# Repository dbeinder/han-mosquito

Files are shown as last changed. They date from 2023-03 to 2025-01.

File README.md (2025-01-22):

# µHAN mosquito

> **_Aus Österreich?:_** Ich habe noch einige Module übrig, bei Interesse bitte Email an david(at)beinder.at
> 
>  Inkl. Versand 37€ für 1 Stk, dann +15€ für jedes weitere. Privatverkauf, Bastellösung, keine Gewährleistung, etc ;)

A tiny [M-BUS](https://m-bus.com/documentation-wired/04-physical-layer)-powered [ESP32-C3](https://www.espressif.com/sites/default/files/documentation/esp32-c3_datasheet_en.pdf) board to capture data from digital electricity meters. Compatible with [AMS reader](https://github.com/UtilitechAS/amsreader-firmware) firmware.

  - Power & flashing via USB-C
  - Power & meter signal via M-BUS (RJ11)
    - Input current limited to 40mA, this is probably only compatible with Kaifa meters
    - Firmware needs no aggressive WiFi power management, there is enough for AP mode and OTA firmware upgrade
  - ESP32-C3-MINI-1 module: 160MHz RISC-V core, 4MB Flash, 400kB RAM, 2.4GHz WiFi
  - 1mm² RGB LED
  - Two side-mounted buttons
    - Top: ESP32 reset
    - Bottom: AP mode, hold during reset to flash
  - Mounted by magnet on the IR port
  - Tested on an Austrian (Vbg) Kaifa MA309M
  - Designed in KiCad 7
  
License: free to use and modify for non-commercial use

panel
proto-mounted

###  Prototype pictures
  
| proto-front  | proto-back |
| --- | --- |
|   | |

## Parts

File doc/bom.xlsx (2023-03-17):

Description | LCSC | Package | Name | Designator | $/pcs | pcs | $ | JLCPCB Extended Part | THT
5303-6P6C | C3097718 |  | RJ11 connector | J1 | 0.072 | 1 | 0.072 | 1 | 1
U264-141N-4BAC10 | C692526 |  | USB-C connector | J2 | 0.7492 | 1 | 0.7492 | 1 | 1
GT-TC018A-H035-L1 | C778153 |  | side NO switch | SW1, SW2 | 0.0291 | 2 | 0.0582 | 1
ESP32-C3-MINI-1-H4 | C2934569 |  | ESP32-C3 module | U1 | 2.1063 | 1 | 2.1063 | 1
TP6841S6 | C2844736 | SOT-23-6 | DC/DC, 800kHz | U2 | 0.4169 | 1 | 0.4169 | 1
MSK4010 | C345958 | SOD-523 | schottky | D2, D3, D5 | 0.0295 | 3 | 0.0885 | 1
BZX584C6V8 | C83014 | SOD-523 | zener 6V2 | D6 | 0.0268 | 1 | 0.0268 | 1
FC-B1010RGBT-HG | C158099 | 0404 | RGB LED | D7 | 0.0192 | 1 | 0.0192 | 1
AL5809-40S1-7 | C151420 | SOD-123 | diode driver 40mA | D1 | 0.5031 | 1 | 0.5031 | 1
MMBT3906T | C61615 | SOT-523-3 | PNP | Q1 | 0.024 | 1 | 0.024 | 1
NPXC0901V151MF | C2976307 |  | 150uF 35V D6.3mm, H7mm | C1 | 0.164 | 1 | 0.164 | 1 | 1
CL10A226MO7JZNC | C2762594 | 0402 | 22uF, 16V | C4, C5 | 0.0543 | 2 | 0.1086 | 1
GRM188R6YA106MA73D | C194427 | 0402 | 10uF, 35V | C2, C3 | 0.037 | 2 | 0.074 | 1
CL05B104KB54PNC | C307331 | 0402 | 100nF, 50V | C6, C7, C9 | 0.0031 | 3 | 0.0093 | 0
GRM155R6YA225KE11D | C237392 | 0402 | 2.2uF, 35V | C8 | 0.0417 | 1 | 0.0417 | 1
CKST252012-6.8uH/M | C3002554 | 252012 | 6.8uH | L1 | 0.0609 | 1 | 0.0609 | 1
0402WGF7502TCE | C25798 | 0402 | 75k, 1% | R1 | 0.0005 | 1 | 0.0005 | 0
0402WGF2402TCE | C25769 | 0402 | 24k, 1% | R2 | 0.0005 | 1 | 0.0005 | 0
0402WGF1004TCE | C26083 | 0402 | 1M, 1% | R3, R7, R8 | 0.0005 | 3 | 0.0015 | 0
0402WGF3300TCE | C25104 | 0402 | 330R, 1% | R4 | 0.0005 | 1 | 0.0005 | 0
0402WGF2201TCE | C25879 | 0402 | 2.2k, 1% | R5 | 0.0005 | 1 | 0.0005 | 0
0402WGF1001TCE | C11702 | 0402 | 1k, 1% | R6 | 0.0005 | 1 | 0.0005 | 0
0402WGF2003TCE | C25764 | 0402 | 200k, 1% | R9, R12 | 0.0005 | 2 | 0.001 | 0
0402WGF5101TCE | C25905 | 0402 | 5.1k, 1% | R10, R11 | 0.0005 | 1 | 0.0005 | 0

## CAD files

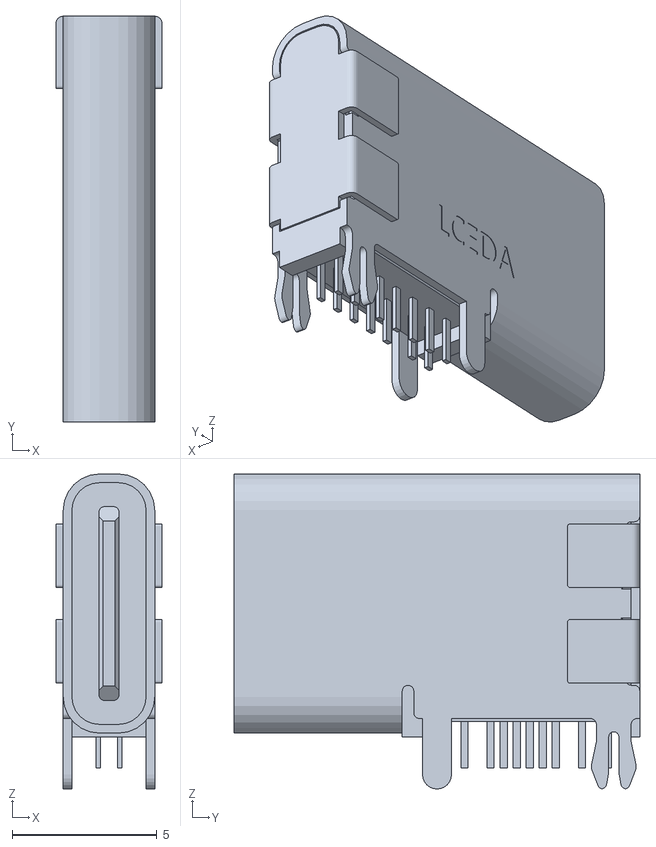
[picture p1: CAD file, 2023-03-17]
mosquito-lib/3d/orig/usbc-19.obj
3.66 x 14.0 x 10.9

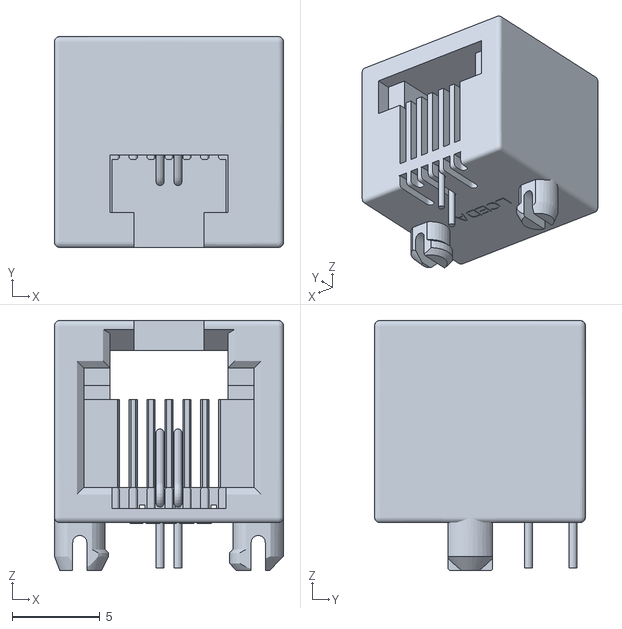
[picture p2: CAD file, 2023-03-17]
mosquito-lib/3d/orig/rj.obj
13.1 x 12.0 x 14.2

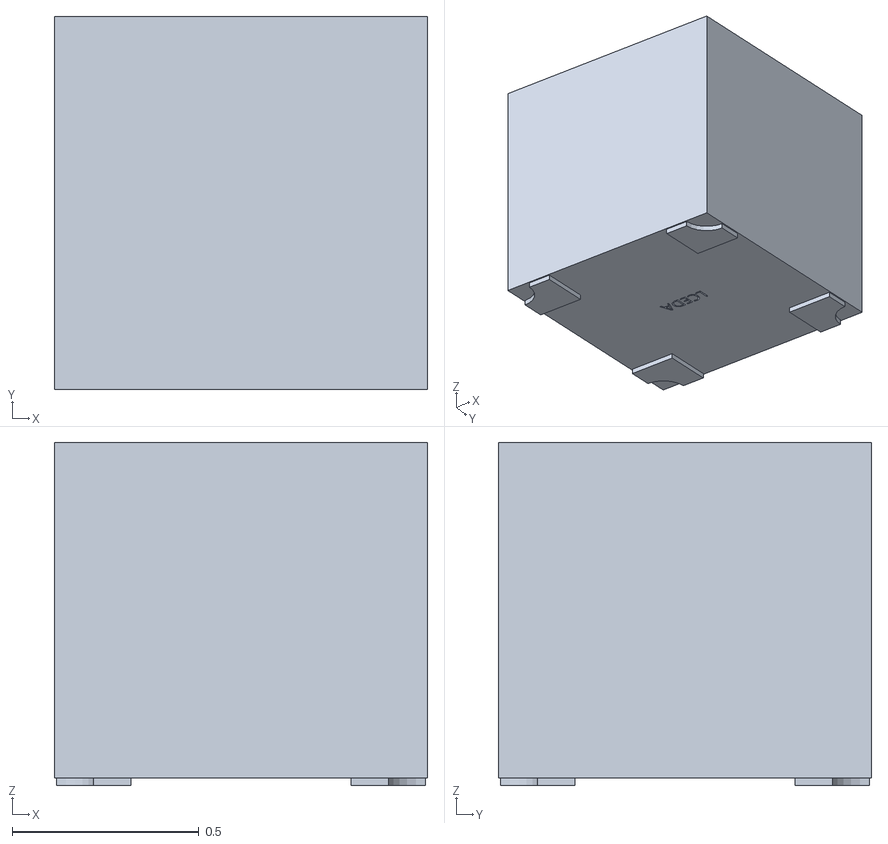
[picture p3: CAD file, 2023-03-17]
mosquito-lib/3d/orig/rgb0404.obj
1.00 x 1.00 x 0.92

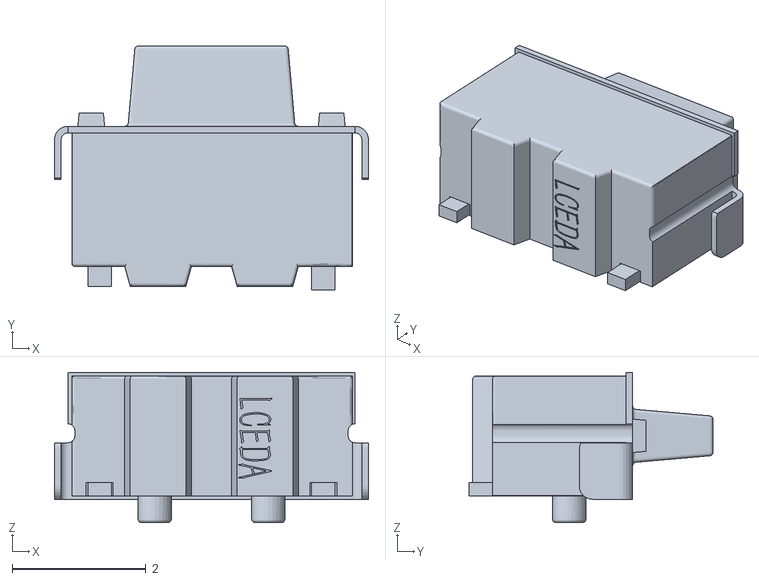
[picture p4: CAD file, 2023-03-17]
mosquito-lib/3d/orig/sw.obj
4.70 x 3.65 x 2.25

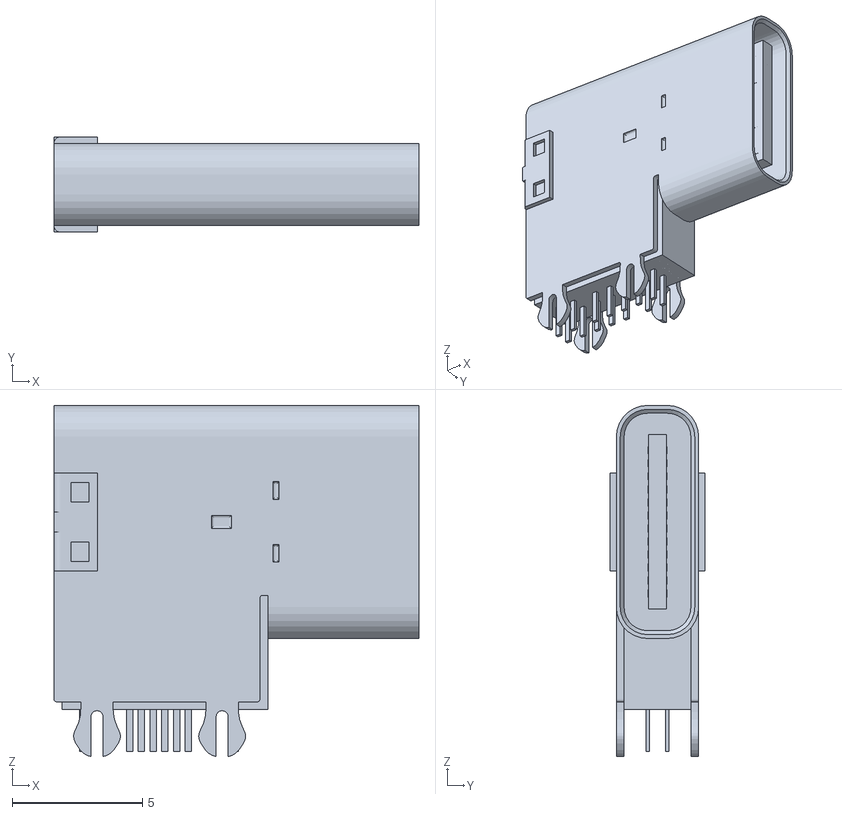
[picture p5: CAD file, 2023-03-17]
mosquito-lib/3d/orig/usbc-18.obj
14.0 x 3.66 x 13.5

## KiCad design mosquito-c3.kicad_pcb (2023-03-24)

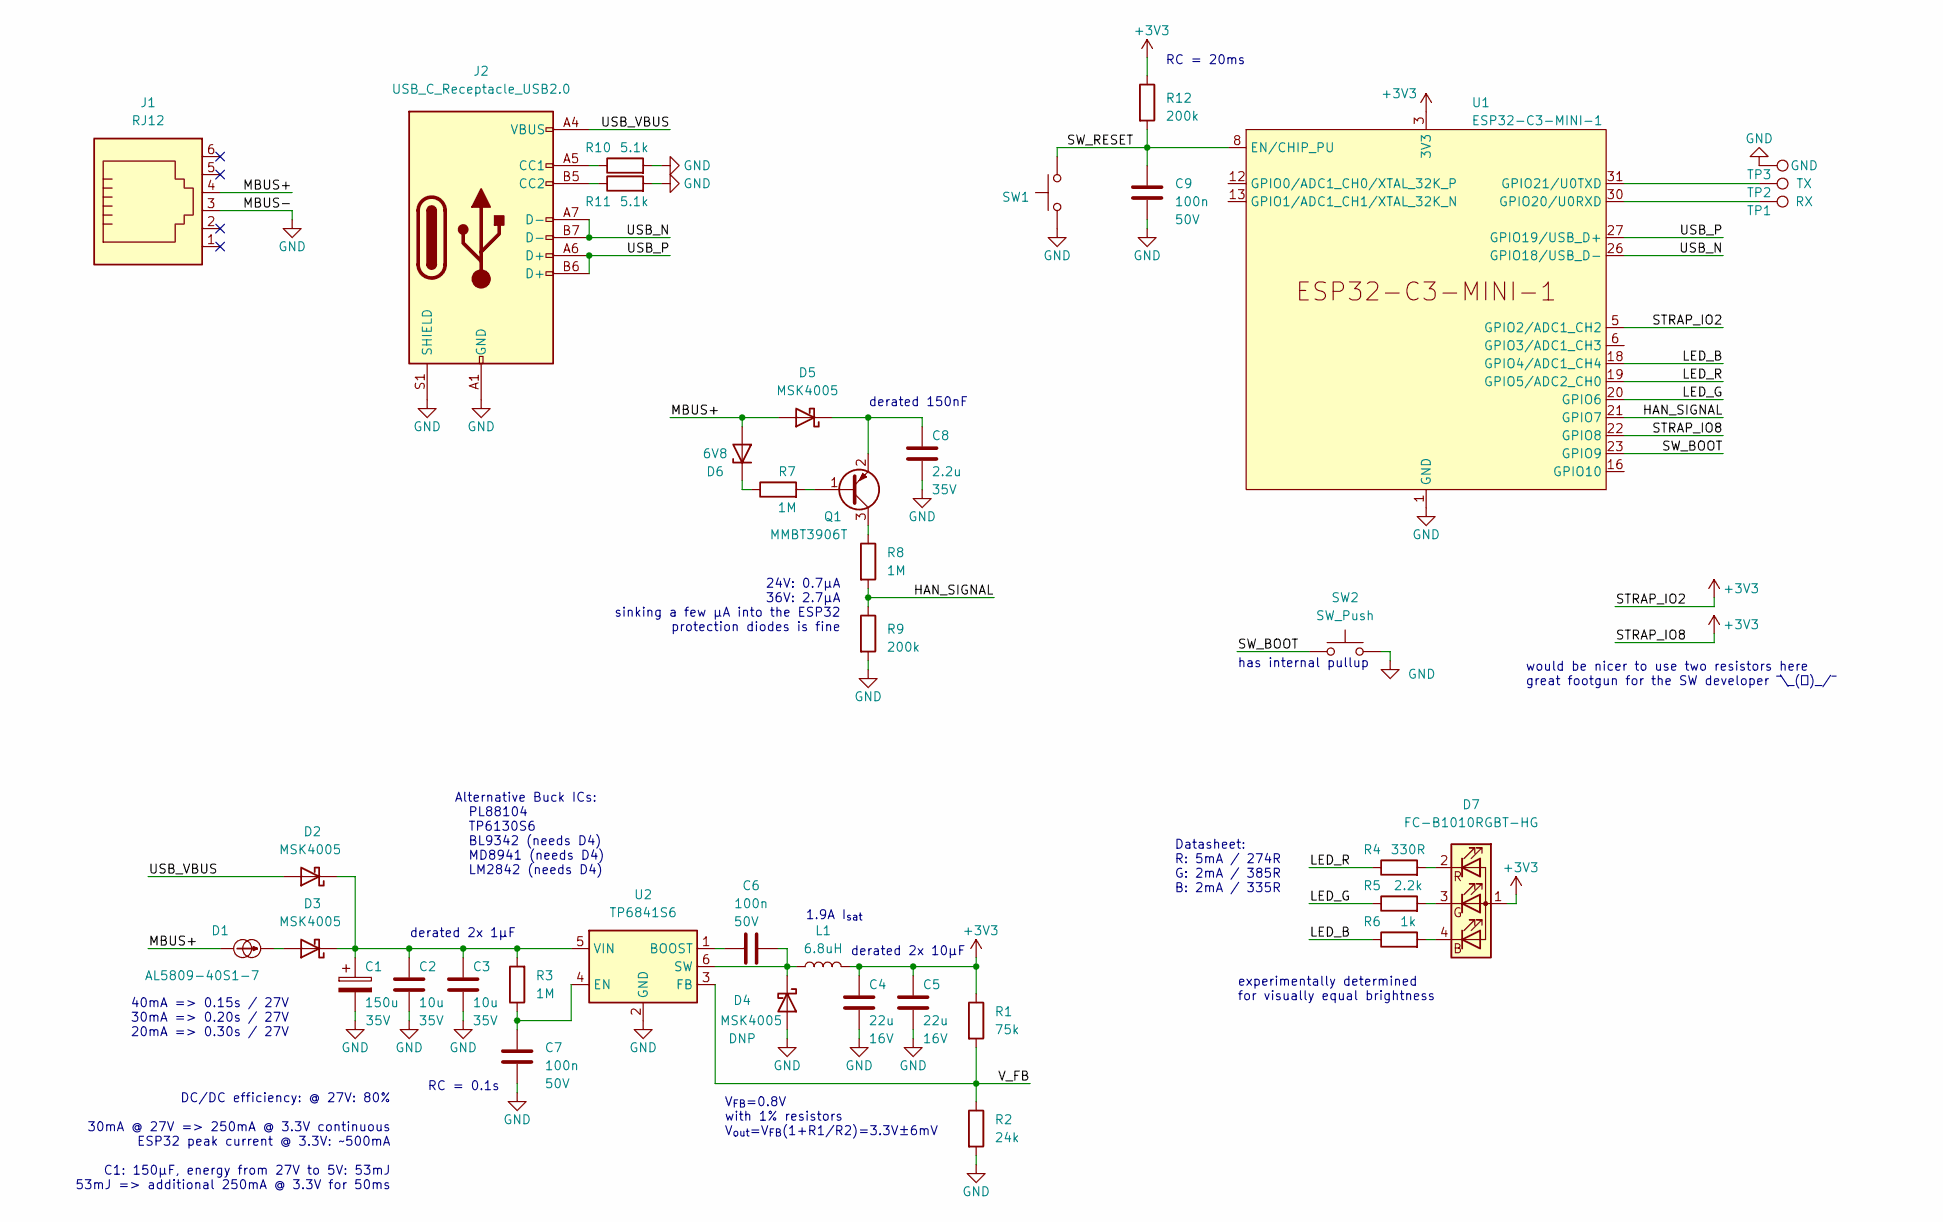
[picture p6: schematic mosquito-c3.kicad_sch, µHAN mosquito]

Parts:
C1: 150u; C_Radial_D6.3mm_H7.0mm_P2.50mm; Voltage 35V
C2, C3: 10u; C_0603_1608Metric; Voltage 35V
C4, C5: 22u; C_0603_1608Metric; Voltage 16V
C6, C7, C9: 100n; C_0402_1005Metric; Voltage 50V
C8: 2.2u; C_0402_1005Metric; Voltage 35V
D1: AL5809-40S1-7; D_SOD-123
D2, D3, D4, D5: MSK4005; D_SOD-523
D6: 6V8; D_SOD-523
D7: FC-B1010RGBT-HG; LED_0404
J1: RJ12; EVERCOM-5303-6P6C
J2: USB_C_Receptacle_USB2.0; TYPE-C-31-M-19
L1: 6.8uH; CKST252012
Q1: MMBT3906T; SOT-523
R1: 75k; R_0402_1005Metric
R2: 24k; R_0402_1005Metric
R3, R7, R8: 1M; R_0402_1005Metric
R4: 330R; R_0402_1005Metric
R5: 2.2k; R_0402_1005Metric
R6: 1k; R_0402_1005Metric
R9, R12: 200k; R_0402_1005Metric
R10, R11: 5.1k; R_0402_1005Metric
SW1, SW2: SW_Push; GT-TC018A
TP1: RX; TestPoint_Pad_D1.0mm
TP2: TX; TestPoint_Pad_D1.0mm
TP3: GND; TestPoint_Pad_D1.0mm
U1: ESP32-C3-MINI-1
U2: TP6841S6; SOT-23-6

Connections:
+3V3: C4.2, C5.2, D7.1 (A), L1.2, R1.1, R12.1, U1.3 (3V3), U1.5 (GPIO2/ADC1_CH2), U1.22 (GPIO8)
/HAN_SIGNAL: R8.2, R9.1, U1.21 (GPIO7)
/LED_B: R6.1, U1.18 (GPIO4/ADC1_CH4)
/LED_G: R5.1, U1.20 (GPIO6)
/LED_R: R4.1, U1.19 (GPIO5/ADC2_CH0)
/MBUS+: D1.2, D5.2 (A), D6.2 (A), J1.4
/SW_BOOT: SW2.2, U1.23 (GPIO9)
/SW_RESET: C9.2, R12.2, SW1.2, U1.8 (EN/CHIP_PU)
/USB_N: J2.A7 (D-), J2.B7 (D-), U1.26 (GPIO18/USB_D-)
/USB_P: J2.A6 (D+), J2.B6 (D+), U1.27 (GPIO19/USB_D+)
/USB_VBUS: D2.2 (A), J2.A4 (VBUS), J2.A9 (VBUS), J2.B4 (VBUS), J2.B9 (VBUS)
/V_FB: R1.2, R2.1, U2.3 (FB)
GND: C1.2, C2.1, C3.1, C4.1, C5.1, C7.1, C8.1, C9.1, D4.2 (A), J1.3, J2.A1 (GND), J2.A12 (GND), J2.B1 (GND), J2.B12 (GND), J2.S1 (SHIELD), R2.2, R9.2, R10.2, R11.2, SW1.1, SW2.1, TP3.1, U1.1 (GND), U1.2 (GND), U1.11 (GND), U1.14 (GND), U1.36 (GND), U1.37 (GND), U1.38 (GND), U1.39 (GND), U1.40 (GND), U1.41 (GND), U1.42 (GND), U1.43 (GND), U1.44 (GND), U1.45 (GND), U1.46 (GND), U1.47 (GND), U1.48 (GND), U1.49 (GND), U1.50 (GND), U1.51 (GND), U1.52 (GND), U1.53 (GND), U2.2 (GND)
unnamed: C1.1, C2.2, C3.2, D2.1 (K), D3.1 (K), R3.2, U2.5 (VIN)
unnamed: D1.1, D3.2 (A)
unnamed: C6.2, D4.1 (K), L1.1, U2.6 (SW)
unnamed: C8.2, D5.1 (K), Q1.2 (E)
unnamed: D6.1 (K), R7.1
unnamed: D7.4 (BK), R6.2
unnamed: D7.3 (GK), R5.2
unnamed: D7.2 (RK), R4.2
unnamed: J2.A5 (CC1), R10.1
unnamed: J2.B5 (CC2), R11.1
unnamed: Q1.1 (B), R7.2
unnamed: Q1.3 (C), R8.1
unnamed: TP1.1, U1.30 (GPIO20/U0RXD)
unnamed: TP2.1, U1.31 (GPIO21/U0TXD)
unnamed: C6.1, U2.1 (BOOST)
unnamed: C7.2, R3.1, U2.4 (EN)

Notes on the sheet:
Alternative Buck ICs: PL88104 TP6130S6 BL9342 (needs D4) MD8941 (needs D4) LM2842 (needs D4)
has internal pullup
experimentally determined for visually equal brightness
DC/DC efficiency: @ 27V: 80% 30mA @ 27V => 250mA @ 3.3V continuous ESP32 peak current @ 3.3V: ~500mA C1: 150µF, energy from 27V to 5V: 53mJ 53mJ => additional 250mA @ 3.3V for 50ms
V_{FB}=0.8V with 1% resistors V_{out}=V_{FB}(1+R1/R2)=3.3V±6mV
derated 2x 10µF
24V: 0.7µA 36V: 2.7µA sinking a few µA into the ESP32 protection diodes is fine
40mA => 0.15s / 27V 30mA => 0.20s / 27V 20mA => 0.30s / 27V
Datasheet: R: 5mA / 274R G: 2mA / 385R B: 2mA / 335R
1.9A I_{sat}
derated 2x 1µF
RC = 0.1s
derated 150nF
would be nicer to use two resistors here great footgun for the SW developer ¯\_(ツ)_/¯
RC = 20ms

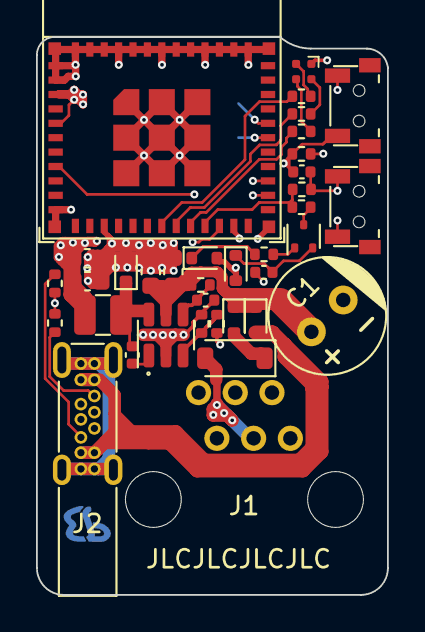
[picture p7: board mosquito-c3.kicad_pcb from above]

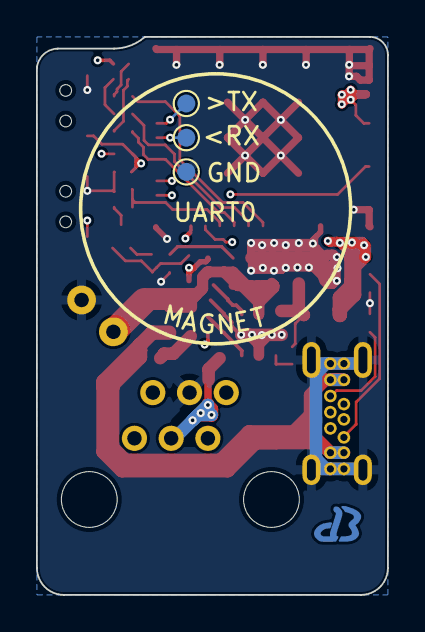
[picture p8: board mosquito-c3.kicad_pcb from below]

Board: 4 copper layers, 19.5 x 31.0 mm, 39 parts (3 on the bottom side), 29 nets.

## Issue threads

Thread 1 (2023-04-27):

[Question] Can be used for NetzNoe ?

Noschvie, 2023-04-27:
Hallo David
bin auf der Suche nach einer Hardware, die die beiden Zähler von NetzNoe unterstützen: externe Power Supply und MBus Interface. Als Firmware möchte ich gerne Tasmota verwenden.
Habe einen ESP32 und das M-Bus Slave Click Board mit Tasmota laufen, soweit ok.
Aber eine kompakte Hardware wie deine wäre mir lieber
mfg
Norbert

dbeinder, 2023-04-27:
Siehe mein Kommentar im anderen Thread: https://github.com/UtilitechAS/amsreader-firmware/discussions/480#discussioncomment-5282325
Ich denke dein MA309 funktioniert mit meiner HW direkt bus-powered, egal was die NetzNoe Spezifikation meint. Andere Meter eher nur mit USB Supply, dazu kann man eine Leiterbahn auf dem PCB durchtrennen um den MBUS nicht zu belasten.

Tasmota sollte schon möglich sein, müsstest du allerdings selbst anpassen. Am RX Pin darf die Firmware keinen Pullup konfigurieren, sonst kommen die Daten nicht richtig an.

Ich habe vor kurzem einige produzieren lassen:
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

Ich kann dir gerne welche zuschicken, sagen wir inkl. Versand 35€ für 1 Stk, +15€ für jedes weitere.
Bei Interesse einfach per Mail an `david (at) beinder.at`

Closed 2023-04-27.

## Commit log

2023-03-17 initial version
    [bom.xlsx, dcdc-comparison.xlsx, mosquito-c3.kicad_pcb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]
2023-03-19 pcb cleanup
    [mosquito-c3.kicad_pcb, mosquito-c3.kicad_sch]
2023-03-24 add KiKit tab/panel hints
    [mosquito-c3.kicad_pcb]
